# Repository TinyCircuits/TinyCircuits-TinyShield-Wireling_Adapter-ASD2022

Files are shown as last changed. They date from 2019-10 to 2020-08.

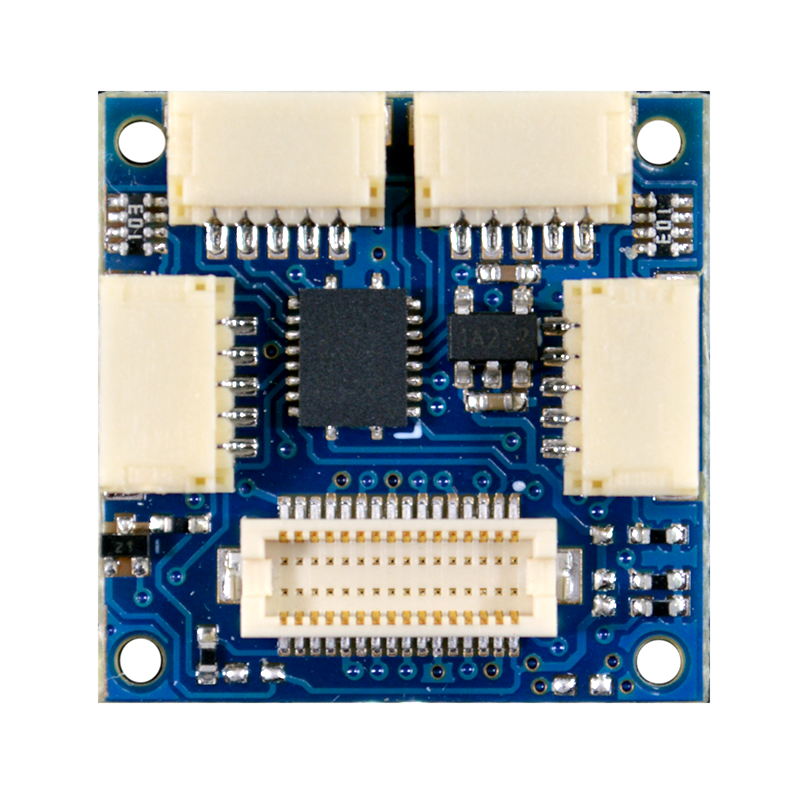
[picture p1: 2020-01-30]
images/ASD2022-Diagram-00.png

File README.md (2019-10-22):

# TinyCircuits TinyShield Wireling Adapter ASD2022
# ASD2022 Rev4

The design files are located under design_files/ for the TinyCircuits ASD2022 Rev 4 PCB. This is a TinyShield that is meant to add 4 separately addressable Wireling Ports to any TinyDuino stack.

Format is in Cadsoft Eagle format - Eagle version 6.2 was used for the original design.

For more infomation on this, check out the product page at TinyCircuits.com

# License:

Design by TinyCircuits.
All design files are released under the Creative Commons Attribution Share-Alike 3.0 License, see the following link for details: http://creativecommons.org/licenses/by-sa/3.0

All text above must be included in any redistribution or derived design

This project uses designs and concepts developed as part of the Arduino project and the LilyPad project.  The TinyCircuits design files themselves (schematics, PCB and libraries) are not directly derived from these works' design files and have been created new, however the concepts and basic architecture behind the TinyDuino and TinyLily products are derived and we thank the hard work of the organizations below for their contributions to open-source hardware:
  
Original Arduino Uno Design by Team Arduino

LilyPad Arduino Design by Leah Buechley and Sparkfun Electronics

Please support the open-source hardware community

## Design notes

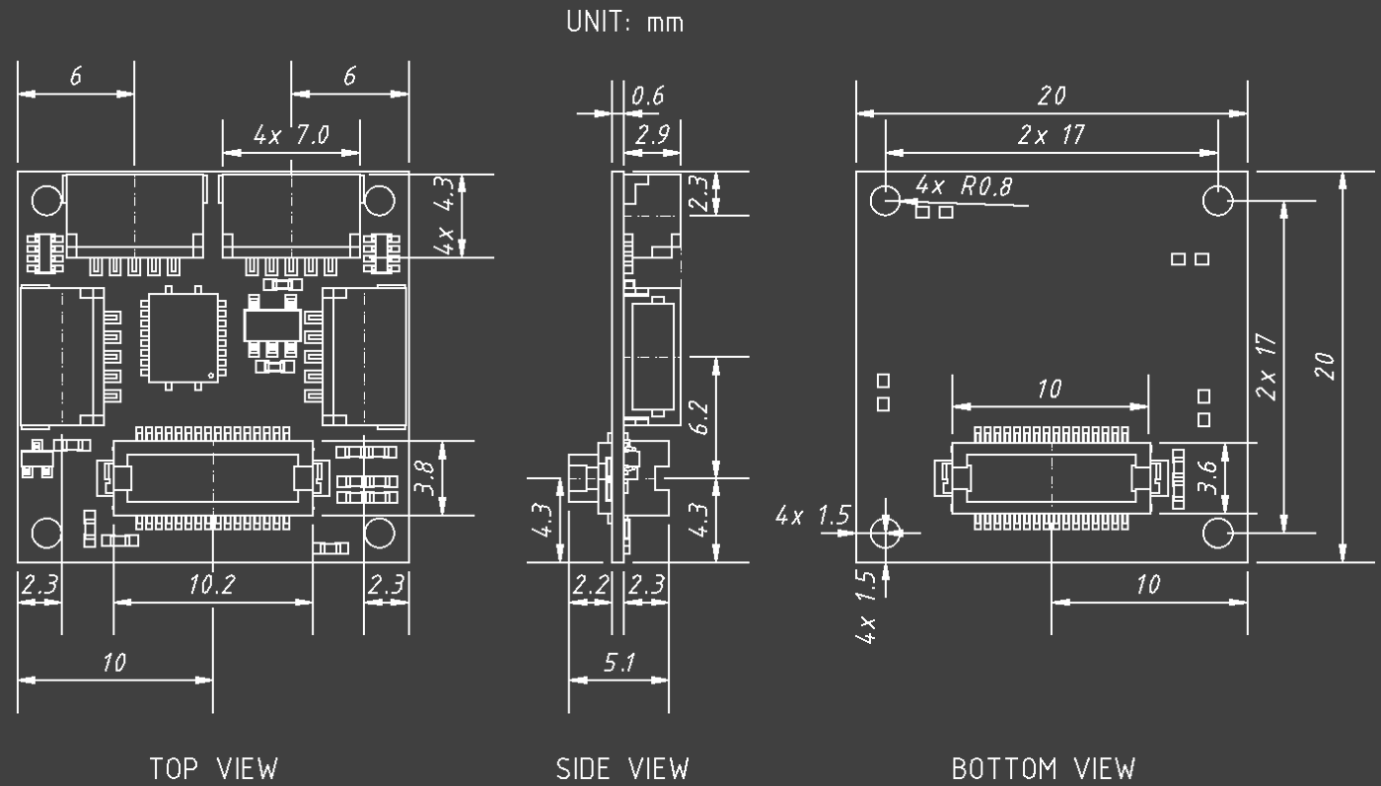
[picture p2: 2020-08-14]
cad/TinyShield_ADAPTER_ASD2022_REV5-DETAILED_DRAWING_COMPACT-PNG.png

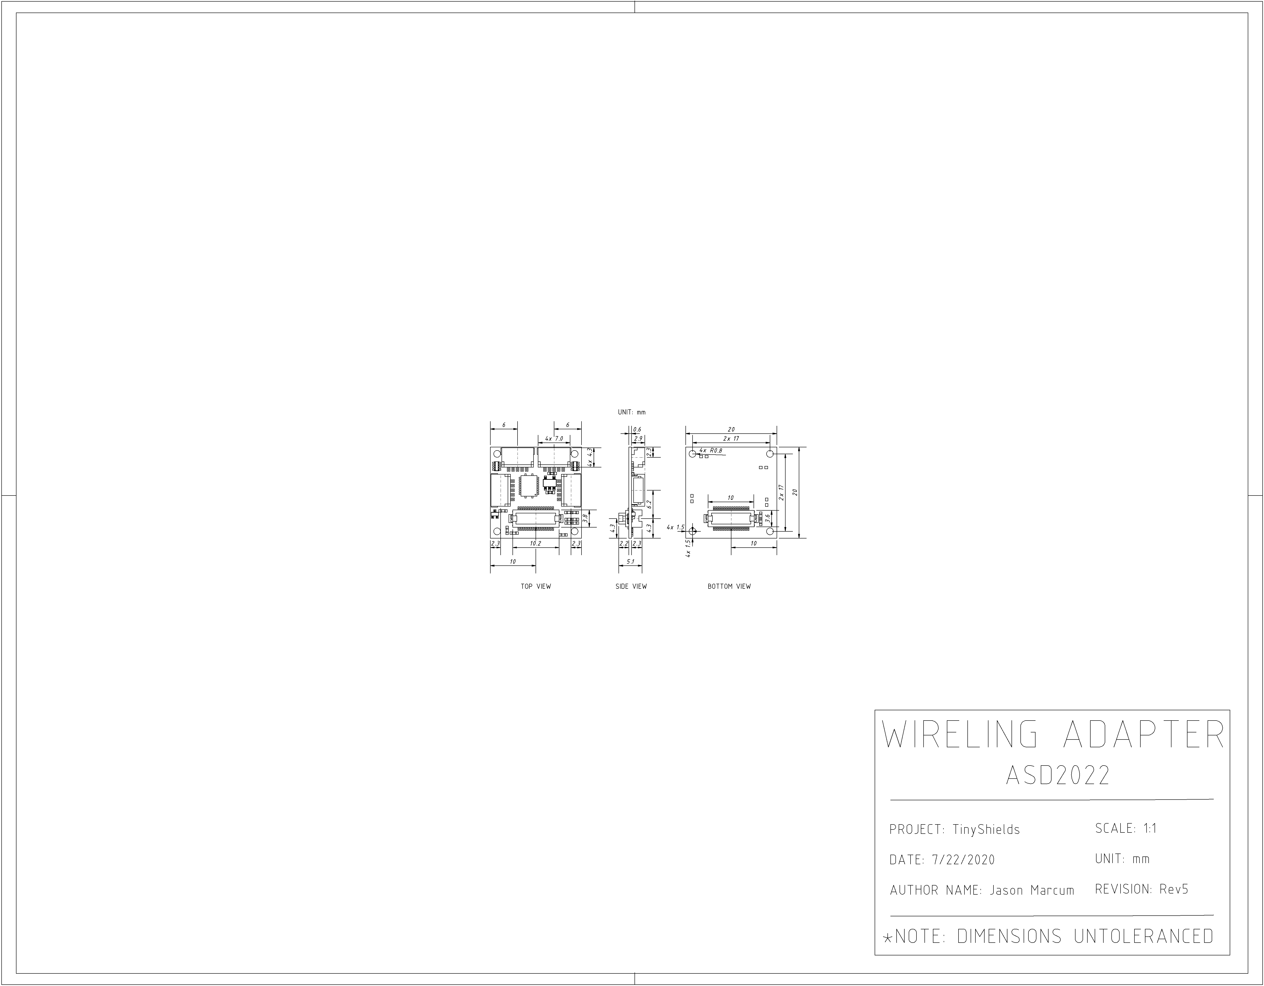
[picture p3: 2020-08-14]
cad/TinyShield_ADAPTER_ASD2022_REV5-DETAILED_DRAWING-PNG.png

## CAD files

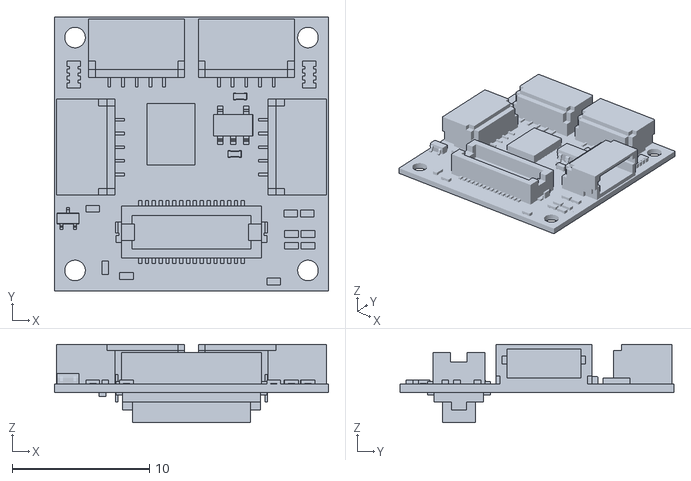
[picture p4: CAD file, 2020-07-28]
cad/TinyShield_ADAPTER_ASD2022_REV5-STL.stl
20.0 x 20.0 x 5.69

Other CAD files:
cad/TinyShield_ADAPTER_ASD2022_REV5-DETAILED_DRAWING-DXF.dxf

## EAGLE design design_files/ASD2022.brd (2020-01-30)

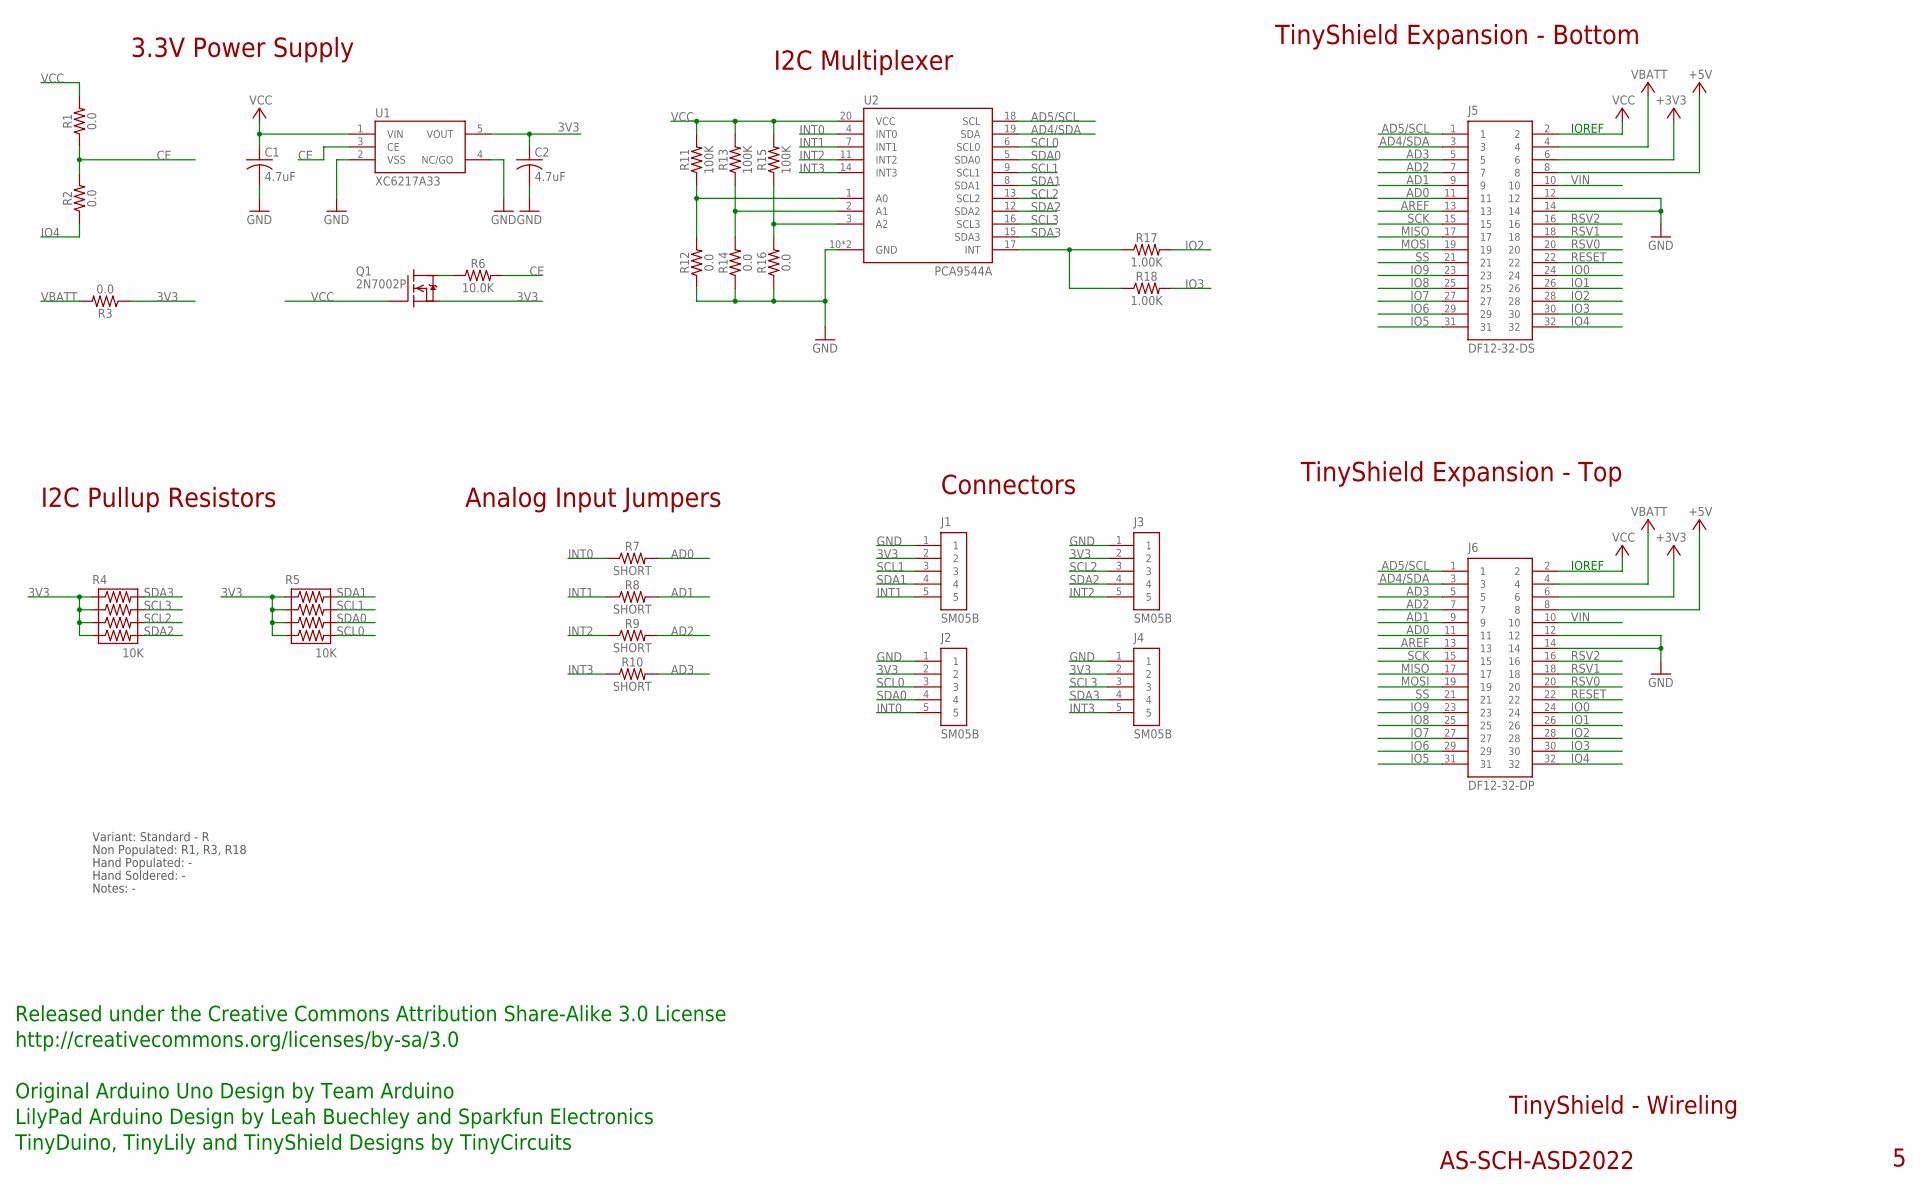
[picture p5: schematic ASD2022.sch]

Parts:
C1, C2: 4.7uF; C0402; PARTNO AS-ITM-00242
J1, J2, J3, J4: SM05B; JST_SH_5X1_EDGE
J5: DF12-32-DS; PARTNO AS-ITM-00012
J6: DF12-32-DP; PARTNO AS-ITM-00015
Q1: 2N7002P; SOT-416; PARTNO AS-ITM-00110
R1, R2, R3, R12, R14, R16: 0.0; 0402; PARTNO AS-ITM-00076
R4, R5: 10K; 0402RPACK; PARTNO AS-ITM-00520
R6: 10.0K; 0402; PARTNO AS-ITM-00032
R7, R8, R9, R10: SHORT; 0402_SHORT
R11, R13, R15: 100K; 0402; PARTNO AS-ITM-00004
R17, R18: 1.00K; 0402
U1: XC6217A33; SOT-25; PARTNO AS-ITM-00249
U2: PCA9544A; VQFN-20_4.5X3.5

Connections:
3V3: C2.1, J1.2, J2.2, J3.2, J4.2, Q1.2 (S), R3.1, R4.1, R4.3, R4.5, R4.7, R5.1, R5.3, R5.5, R5.7, U1.5 (VOUT)
+3V3: J5.6, J6.6
+5V: J5.8, J6.8
AD0: J5.11, J6.11, R7.2
AD1: J5.9, J6.9, R8.2
AD2: J5.7, J6.7, R9.2
AD3: J5.5, J6.5, R10.2
AD4/SDA: J5.3, J6.3, U2.19 (SDA)
AD5/SCL: J5.1, J6.1, U2.18 (SCL)
AREF: J5.13, J6.13
CE: R1.1, R2.2, R6.2, U1.3 (CE)
GND: C1.2, C2.2, J1.1, J2.1, J3.1, J4.1, J5.12, J5.14, J6.12, J6.14, R12.1, R14.1, R16.1, U1.2 (VSS), U1.4 (NC/GO), U2.10 (GND), U2.PAD (GND)
INT0: J2.5, R7.1, U2.4 (INT0)
INT1: J1.5, R8.1, U2.7 (INT1)
INT2: J3.5, R9.1, U2.11 (INT2)
INT3: J4.5, R10.1, U2.14 (INT3)
IO0: J5.24, J6.24
IO1: J5.26, J6.26
IO2: J5.28, J6.28, R17.2
IO3: J5.30, J6.30, R18.2
IO4: J5.32, J6.32, R2.1
IO5: J5.31, J6.31
IO6: J5.29, J6.29
IO7: J5.27, J6.27
IO8: J5.25, J6.25
IO9: J5.23, J6.23
MISO: J5.17, J6.17
MOSI: J5.19, J6.19
unnamed: Q1.3 (D), R6.1
unnamed: R11.1, R12.2, U2.1 (A0)
unnamed: R15.1, R16.2, U2.3 (A2)
unnamed: R17.1, R18.1, U2.17 (INT)
unnamed: R13.1, R14.2, U2.2 (A1)
RESET: J5.22, J6.22
RSV0: J5.20, J6.20
RSV1: J5.18, J6.18
RSV2: J5.16, J6.16
SCK: J5.15, J6.15
SCL0: J2.3, R5.8, U2.6 (SCL0)
SCL1: J1.3, R5.4, U2.9 (SCL1)
SCL2: J3.3, R4.6, U2.13 (SCL2)
SCL3: J4.3, R4.4, U2.16 (SCL3)
SDA0: J2.4, R5.6, U2.5 (SDA0)
SDA1: J1.4, R5.2, U2.8 (SDA1)
SDA2: J3.4, R4.8, U2.12 (SDA2)
SDA3: J4.4, R4.2, U2.15 (SDA3)
SS: J5.21, J6.21
VBATT: J5.4, J6.4, R3.2
VCC: C1.1, J5.2, J6.2, Q1.1 (G), R1.2, R11.2, R13.2, R15.2, U1.1 (VIN), U2.20 (VCC)
VIN: J5.10, J6.10

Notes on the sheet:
TinyShield Expansion - Bottom
TinyShield - Wireling
AS-SCH-ASD2022
TinyShield Expansion - Top
IOREF
Released under the Creative Commons Attribution Share-Alike 3.0 License
http://creativecommons.org/licenses/by-sa/3.0
LilyPad Arduino Design by Leah Buechley and Sparkfun Electronics
TinyDuino, TinyLily and TinyShield Designs by TinyCircuits
Original Arduino Uno Design by Team Arduino
3.3V Power Supply
I2C Multiplexer
Connectors
Analog Input Jumpers
I2C Pullup Resistors
Non Populated: R1, R3, R18
Hand Populated: -
Hand Soldered: -
Notes: -
Variant: Standard - R

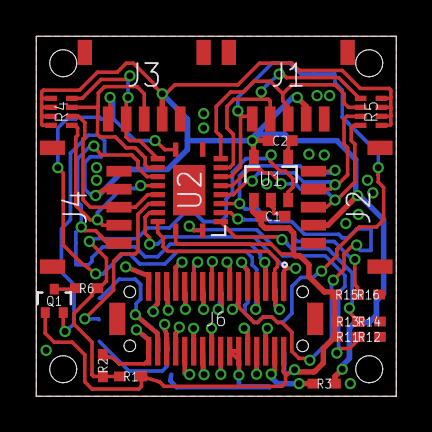
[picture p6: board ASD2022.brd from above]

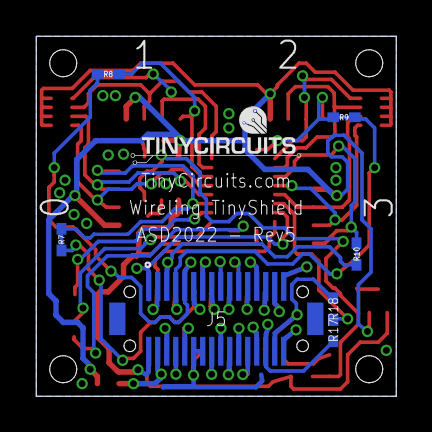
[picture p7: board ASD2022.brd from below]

Board: 2 copper layers, 20.0 x 20.0 mm, 30 parts (7 on the bottom side), 50 nets.

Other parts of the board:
U$1: DOCFIELD-TINYCIRCUITS-PCB

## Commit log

2020-05-26 updated resistor numbers to match new schematic
2020-07-28 Add CAD data
    [TinyShield_ADAPTER_ASD2022_REV5-DETAILED_DRAWING-DXF.dxf, TinyShield_ADAPTER_ASD2022_REV5-STL.stl]
2020-08-14 Update CAD drawing
    [TinyShield_ADAPTER_ASD2022_REV5-DETAILED_DRAWING-DXF.dxf]
